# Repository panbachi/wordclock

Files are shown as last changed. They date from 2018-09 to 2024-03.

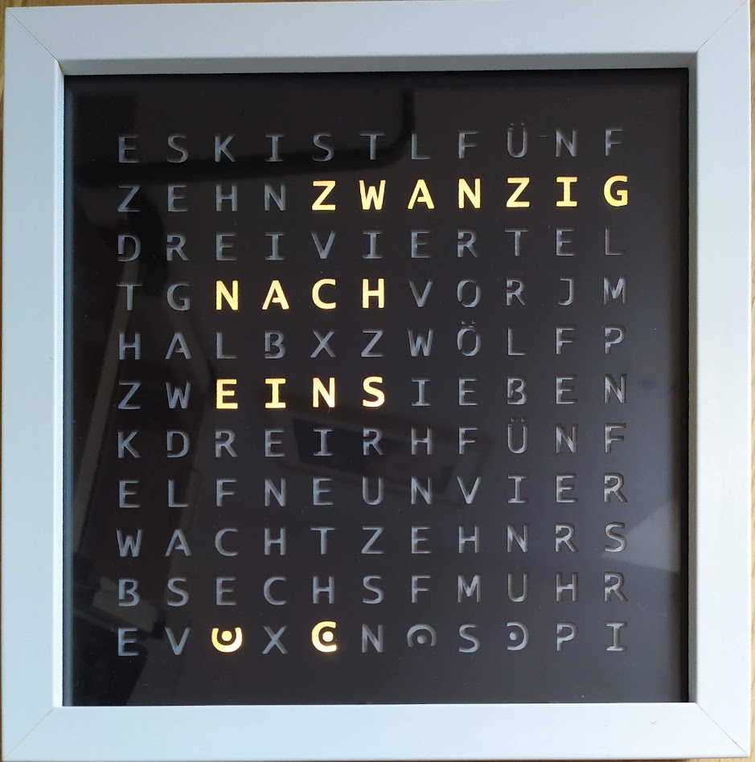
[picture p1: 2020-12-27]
graphics/plate/DE_de_s1.jpg

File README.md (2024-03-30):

# WordClock
 



**Font and german layout based on https://www.mikrocontroller.net/articles/Word_Clock**

# Requirements

## Healthcheck
* [FastLED](https://github.com/FastLED/FastLED)

## WordClock
* [FastLED](https://github.com/FastLED/FastLED)
* [NTPClient](https://github.com/arduino-libraries/NTPClient)
* [WifiManager](https://github.com/tzapu/WiFiManager)
* [ArduinoJson](https://github.com/bblanchon/ArduinoJson)

# Assemble
Word-Clock - Die WLAN Wort-Uhr zum selber bauen (https://www.youtube.com/watch?v=FvAM1t0tISE)

# Customizations
## Modify `user_config.h` to change config
| Key | Values | Comment |
|---|---|---|
| GRID_ROWS | 10<br>11 | count of rows |
| GRID_COLS | 11 | count of cols |
| GRID_FIRST | 0: top-left<br>1: top-right<br>2: buttom-left<br>3: buttom-right | position of first led |
| GRID_LANGUAGE | de_DE: german<br>de_DE_alt: german alternative | langauge |
| GRID_SINGLE_MINUTES | 0: before<br>1: after | position of minutes leds |

# Installation
Make your Arduino ready for Wemos D1 mini e.g. https://makesmart.net/blog/read/esp8266-d1-mini-programmieren-der-start-mit-der-arduino-ide
- Change the grid settings in the `wordclock/user_config.h`.
- Upload the sketch `wordclock/wordclock.ino` to your Wemos D1 mini (or other ESP8266).
- Enjoy

# Usage
The WordClock creates a WiFi-Hotspot with the name "WordClock". Connect e.g. your smartphone to the hotspot and you will be forwared to the config page, where you can set the WiFi credentials.
Check in your router what IP-adress your WordClock got. Open a webbrowser and go to `http://[YOUR_WORDCLOCK_IP]`. For (example) the IP-adress `192.168.178.20` go to `http://192.168.178.20`.

# Functions

## Set color
You can set a foreground and background color on your clock.

## Set time offset
You can set a time offset to specify your timezone.

## Set DND
You can set a time span in which the clock should be switched off.

## PWA
You can use the webbrowser function "Add to start screen" to install the webinterface as an app to your android (and possibly ios) smartphone.

# Create own grid-layout
To create your own grid-layout visit the Wiki: [Create Grid-Layout](https://github.com/panbachi/wordclock/wiki/Create-Grid-Layout)

# Support me / Follow me






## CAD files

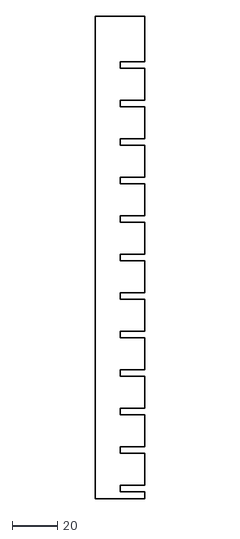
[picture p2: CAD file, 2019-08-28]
graphics/grid/grid_element_medium.dxf
22.0 x 213.0

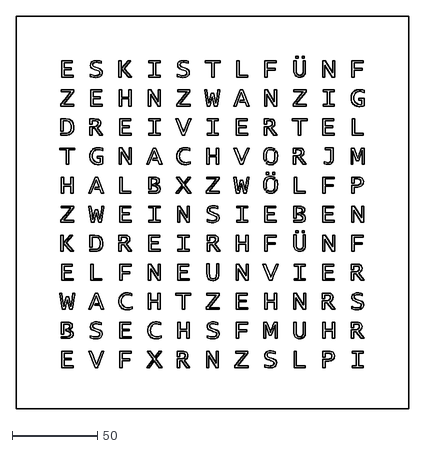
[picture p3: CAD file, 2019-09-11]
graphics/plate/de.dxf
230.0 x 230.0

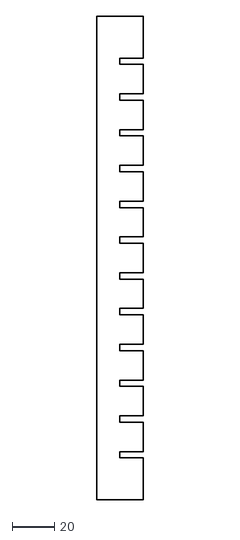
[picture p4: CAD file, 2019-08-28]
graphics/grid/grid_element_large.dxf
22.0 x 230.0

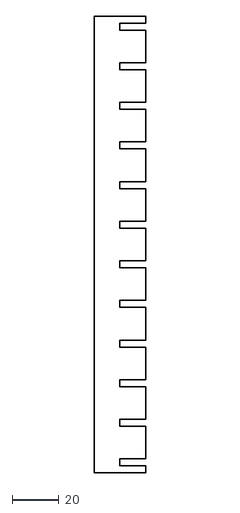
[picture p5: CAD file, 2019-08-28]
graphics/grid/grid_element_small.dxf
22.0 x 196.0

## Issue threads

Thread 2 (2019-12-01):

Minutenanzeige,

christianvoss90, 2019-12-01:
Vielen Dank erstmal für den schönen Code ;-)
Ich habe den Code bei mir um eine Minutenanzeige erweitert (in jeder Ecke der Uhr eine LED, die dann die Minuten 1-4, die auf die angezeigte Zeit addiert werden müssen, anzeigen).
Dabei ist mir aufgefallen, das mit dem originalen Code die Uhr eine Minute nach geht. Das Problem habe ich in Zeile 638 bis 642 (Originaler Code) gefunden. Die Zeilen 640 & 641 müssen vor den Zeilen 638 & 339 kommen (es müssen erst die Minuten und Stunden in die Variablen geschrieben werden, und dann das "show()" aufgerufen werden.
Dann habe ich den Code noch so angepasst, dass im setup einmal das Setzen der Zeitzone (die ich beim deklarieren der Variable: int offset = 1;) ausgeführt wird. So muss ich nicht nach jedem reboot des Controllers die Zeit neu setzten. Ausserdem habe ich den Code so angepasst, dass um 1:00 Uhr nicht "ES IST EINS UHR" erscheint, sondern auf das S verzichtet wird.

Vielleicht ist es ja etwas für den Code, oder jemand anderes kann damit auch was anfangen.

Hier einmal mein Code:

```
#include <ESP8266WiFi.h>
#include <ESP8266WebServer.h>
#include <FastLED.h>
#include <NTPClient.h>
#include <WiFiUdp.h>

#define NUM_LEDS 125
#define DATA_PIN D4

/**********************
 * SET WIFI CREDENTIALS
 **********************/
const char* ssid  = "DeinWlanName";
const char* password = "DeinWlanSchlüssel";

typedef struct {
  int r;
  int g;
  int b;
} color_t;

typedef struct {
  int pixel;
  int r;
  int g;
  int b;
} pixel_color_t;

int time_it_is[] = {110, 111, 113, 114, 115};// ES IST

int time_minutes[][12] = {
  { 13,  12,  11,  -1,  -1,  -1,  -1,  -1,  -1,  -1,  -1,  -1},//UHR
  {117, 118, 119, 120,  85,  84,  83,  82,  -1,  -1,  -1,  -1},//FÜNF NACH
  {109, 108, 107, 106,  85,  84,  83,  82,  -1,  -1,  -1,  -1},//ZEHN NACH
  { 92,  93,  94,  95,  96,  97,  98,  85,  84,  83,  82,  -1},//VIERTEL NACH
  {105, 104, 103, 102, 101, 100,  99,  85,  84,  83,  82,  -1},//ZWANZIG NACH
  {117, 118, 119, 120,  81,  80,  79,  66,  67,  68,  69,  -1},//FÜNF VOR HALB
  { 66,  67,  68,  69,  -1,  -1,  -1,  -1,  -1,  -1,  -1,  -1},//HALB
  {117, 118, 119, 120,  85,  84,  83,  82,  66,  67,  68,  69},//FÜNF NACH HALB
  {105, 104, 103, 102, 101, 100,  99,  81,  80,  79,  -1,  -1},//ZWANZIG VOR
  { 92,  93,  94,  95,  96,  97,  98,  81,  80,  79,  -1,  -1},//VIERTEL VOR
  {109, 108, 107, 106,  81,  80,  79,  -1,  -1,  -1,  -1,  -1},//ZEHN VOR
  {117, 118, 119, 120,  81,  80,  79,  -1,  -1,  -1,  -1,  -1} //FÜNF VOR
};

int time_hours[][6] = {
  {71, 72, 73, 74, 75, -1},//ZWÖLF
  {63, 62, 61, 60, -1, -1},//EINS
  {65, 64, 63, 62, -1, -1},//ZWIE
  {45, 46, 47, 48, -1, -1},//DREI
  {36, 35, 34, 33, -1, -1},//VIER
  {51, 52, 53, 54, -1, -1},//FÜNF
  {20, 19, 18, 17, 16, -1},//SECHS
  {60, 59, 58, 57, 56, 55},//SIEBEN
  {23, 24, 25, 26, -1, -1},//ACHT
  {40, 39, 38, 37, -1, -1},//NEUN
  {27, 28, 29, 30, -1, -1},//ZEHN
  {43, 42, 41, -1, -1, -1},//ELF
  {63, 62, 61, -1, -1, -1},//EIN
};

int time_ecken[][4] = {
  {-1, -1, -1, -1}, // ALLE AUS
  {122, -1, -1, -1}, //OBEN LINKS
  {122, 121, -1, -1},// +OBEN RECHTS
  {122, 121, 123, -1},//+UNTEN LINKS
  {122, 121, 123, 124},//+UNTEN RECHTS
};

int degree_minus[] = {108, 107, 106, 105};

int degree_symbol[] = { 119, 101, 99, 97};

int degree_10[] = {70, 61, 48, 39, 26, 17, 4};
int degree_20[] = {67, 68, 69, 70, 61, 48, 42, 41, 40, 39, 23, 20, 1, 2, 3, 4};
int degree_30[] = {67, 68, 69, 70, 61, 48, 42, 41, 40, 39, 26, 17, 1, 2, 3, 4};
int degree_40[] = {67, 70, 64, 61, 45, 48, 42, 41, 40, 39, 26, 17, 4};

int degree_0[] = {72, 73, 74, 75, 59, 56, 50, 53, 37, 34, 28, 31, 15, 12, 6, 7, 8, 9};
int degree_1[] = {75, 56, 53, 34, 31, 12, 9};
int degree_2[] = {72, 73, 74, 75, 56, 53, 37, 36, 35, 34, 28, 15, 6, 7, 8, 9};
int degree_3[] = {72, 73, 74, 75, 56, 53, 37, 36, 35, 34, 31, 12, 6, 7, 8, 9};
int degree_4[] = {72, 75, 59, 56, 50, 53, 37, 36, 35, 34, 31, 12, 9};
int degree_5[] = {72, 73, 74, 75, 59, 50, 37, 36, 35, 34, 31, 12, 6, 7, 8, 9};
int degree_6[] = {72, 73, 74, 75, 59, 50, 37, 36, 35, 34, 28, 31, 15, 12, 6, 7, 8, 9};
int degree_7[] = {72, 73, 74, 75, 56, 53, 34, 31, 12, 9};
int degree_8[] = {72, 73, 74, 75, 59, 56, 50, 53, 37, 36, 35, 34, 28, 31, 15, 12, 6, 7, 8, 9};
int degree_9[] = {72, 73, 74, 75, 59, 56, 50, 53, 37, 36, 35, 34, 31, 12, 6, 7, 8, 9};

pixel_color_t icon_snow[] = {
  { 5, 212, 223, 244 }, { 6, 176, 208, 247 }, { 7, 169, 206, 246 }, { 8, 207, 229, 249 }, { 14, 213, 232, 249 },
  { 15, 114, 175, 239 }, { 16, 86, 159, 237 }, { 17, 86, 159, 237 }, { 18, 155, 198, 244 }, { 19, 233, 233, 233 },
  { 23, 255, 255, 255 }, { 24, 201, 223, 245 }, { 25, 168, 203, 245 }, { 26, 171, 205, 245 }, { 27, 96, 165, 238 },
  { 28, 86, 159, 237 }, { 29, 86, 159, 237 }, { 30, 86, 159, 237 }, { 31, 200, 224, 249 }, { 34, 229, 246, 255 },
  { 35, 193, 220, 245 }, { 36, 166, 205, 244 }, { 37, 86, 159, 237 }, { 38, 86, 159, 237 }, { 39, 86, 159, 237 },
  { 40, 86, 159, 237 }, { 41, 86, 159, 237 }, { 42, 86, 159, 237 }, { 43, 94, 164, 238 }, { 44, 202, 223, 246 },
  { 45, 168, 205, 244 }, { 46, 86, 159, 237 }, { 47, 86, 159, 237 }, { 48, 86, 159, 237 }, { 49, 86, 159, 237 },
  { 50, 86, 159, 237 }, { 51, 86, 159, 237 }, { 52, 86, 159, 237 }, { 53, 86, 159, 237 }, { 54, 86, 160, 237 },
  { 55, 191, 219, 247 }, { 56, 166, 203, 245 }, { 57, 86, 159, 237 }, { 58, 86, 159, 237 }, { 59, 86, 159, 237 },
  { 60, 86, 159, 237 }, { 61, 86, 159, 237 }, { 62, 86, 159, 237 }, { 63, 86, 159, 237 }, { 64, 86, 159, 237 },
  { 65, 86, 159, 237 }, { 66, 168, 205, 244 }, { 67, 202, 223, 246 }, { 68, 96, 165, 238 }, { 69, 86, 159, 237 },
  { 70, 89, 161, 237 }, { 71, 93, 163, 238 }, { 72, 86, 159, 237 }, { 73, 86, 159, 237 }, { 74, 86, 159, 237 },
  { 75, 86, 159, 237 }, { 76, 86, 159, 237 }, { 77, 184, 215, 245 }, { 78, 204, 221, 238 }, { 79, 180, 212, 245 },
  { 80, 148, 194, 242 }, { 81, 210, 228, 245 }, { 82, 156, 199, 241 }, { 83, 145, 193, 242 }, { 84, 193, 219, 244 },
  { 85, 182, 214, 243 }, { 86, 161, 201, 244 }, { 87, 198, 220, 245 }, { 88, 176, 176, 176 }, { 91, 187, 187, 187 },
  { 92, 225, 225, 225 }, { 93, 225, 225, 225 }, { 94, 225, 225, 225 }, { 95, 226, 226, 226 }, { 96, 244, 244, 238 },
  { 97, 225, 225, 225 }, { 103, 237, 237, 237 }, { 104, 139, 139, 139 }, { 106, 246, 246, 237 }, { 107, 239, 239, 235 },
  { 114, 245, 245, 236 }, { 115, 241, 241, 241 }, { 117, 231, 231, 231 }, { 118, 251, 251, 243 }
};

pixel_color_t icon_thunder[] = {
  { 5, 206, 226, 244 }, { 6, 172, 208, 247 }, { 7, 165, 204, 244 }, { 8, 201, 224, 249 }, { 14, 213, 231, 249 },
  { 15, 110, 173, 239 }, { 16, 86, 159, 237 }, { 17, 86, 159, 237 }, { 18, 152, 195, 243 }, { 19, 239, 239, 239 },
  { 20, 255, 255, 255 }, { 23, 223, 223, 223 }, { 24, 193, 220, 247 }, { 25, 157, 198, 243 }, { 26, 171, 207, 245 },
  { 27, 114, 175, 240 }, { 28, 107, 172, 239 }, { 29, 97, 166, 238 }, { 30, 86, 159, 237 }, { 31, 199, 224, 246 },
  { 34, 217, 233, 249 }, { 35, 182, 212, 243 }, { 36, 156, 197, 243 }, { 37, 86, 159, 237 }, { 38, 211, 211, 197 },
  { 39, 239, 193, 104 }, { 40, 241, 198, 118 }, { 41, 230, 217, 185 }, { 42, 86, 159, 237 }, { 43, 89, 161, 237 },
  { 44, 196, 219, 245 }, { 45, 166, 204, 244 }, { 46, 86, 159, 237 }, { 47, 86, 159, 237 }, { 48, 99, 166, 238 },
  { 49, 230, 207, 156 }, { 50, 254, 164, 0 }, { 51, 237, 198, 122 }, { 52, 102, 168, 239 }, { 53, 86, 159, 237 },
  { 54, 86, 159, 237 }, { 55, 185, 214, 246 }, { 56, 164, 201, 243 }, { 57, 86, 159, 237 }, { 58, 86, 159, 237 },
  { 59, 230, 217, 185 }, { 60, 254, 171, 12 }, { 61, 250, 178, 46 }, { 62, 230, 217, 185 }, { 63, 86, 159, 237 },
  { 64, 86, 159, 237 }, { 65, 86, 159, 237 }, { 66, 172, 207, 243 }, { 67, 206, 224, 246 }, { 68, 115, 175, 239 },
  { 69, 86, 159, 237 }, { 70, 181, 209, 234 }, { 71, 230, 217, 185 }, { 72, 243, 194, 99 }, { 73, 254, 164, 0 },
  { 74, 215, 207, 181 }, { 75, 86, 159, 237 }, { 76, 89, 160, 237 }, { 77, 192, 219, 246 }, { 78, 203, 214, 214 },
  { 79, 195, 218, 245 }, { 80, 174, 208, 243 }, { 81, 233, 227, 208 }, { 82, 250, 178, 46 }, { 83, 254, 180, 46 },
  { 84, 232, 223, 203 }, { 85, 170, 207, 243 }, { 86, 178, 211, 245 }, { 87, 207, 221, 240 }, { 93, 165, 165, 165 },
  { 94, 251, 228, 183 }, { 95, 243, 194, 99 }, { 96, 92, 92, 92 }, { 103, 249, 233, 209 }, { 104, 237, 198, 122 },
  { 105, 208, 208, 208 }, { 117, 228, 228, 228 }, { 118, 251, 242, 225 }
};

pixel_color_t icon_rain[] = {
  { 5, 206, 226, 244 }, { 6, 174, 207, 243 }, { 7, 165, 204, 244 }, { 8, 203, 226, 249 }, { 14, 213, 231, 249 },
  { 15, 110, 173, 239 }, { 16, 86, 159, 237 }, { 17, 86, 159, 237 }, { 18, 152, 195, 243 }, { 19, 239, 239, 239 },
  { 20, 255, 255, 255 }, { 23, 223, 223, 223 }, { 24, 193, 220, 247 }, { 25, 155, 198, 243 }, { 26, 158, 200, 244 },
  { 27, 93, 163, 238 }, { 28, 86, 159, 237 }, { 29, 86, 159, 237 }, { 30, 86, 159, 237 }, { 31, 199, 224, 246 },
  { 34, 218, 228, 244 }, { 35, 182, 212, 245 }, { 36, 154, 196, 243 }, { 37, 86, 159, 237 }, { 38, 86, 159, 237 },
  { 39, 86, 159, 237 }, { 40, 86, 159, 237 }, { 41, 86, 159, 237 }, { 42, 86, 159, 237 }, { 43, 89, 161, 237 },
  { 44, 196, 219, 245 }, { 45, 166, 204, 244 }, { 46, 86, 159, 237 }, { 47, 86, 159, 237 }, { 48, 86, 159, 237 },
  { 49, 86, 159, 237 }, { 50, 86, 159, 237 }, { 51, 86, 159, 237 }, { 52, 86, 159, 237 }, { 53, 86, 159, 237 },
  { 54, 86, 159, 237 }, { 55, 185, 215, 245 }, { 56, 166, 203, 245 }, { 57, 86, 159, 237 }, { 58, 86, 159, 237 },
  { 59, 86, 159, 237 }, { 60, 86, 159, 237 }, { 61, 86, 159, 237 }, { 62, 86, 159, 237 }, { 63, 86, 159, 237 },
  { 64, 86, 159, 237 }, { 65, 86, 159, 237 }, { 66, 172, 207, 243 }, { 67, 205, 224, 246 }, { 68, 116, 175, 239 },
  { 69, 86, 159, 237 }, { 70, 86, 159, 237 }, { 71, 86, 159, 237 }, { 72, 86, 159, 237 }, { 73, 86, 159, 237 },
  { 74, 86, 159, 237 }, { 75, 86, 159, 237 }, { 76, 89, 161, 237 }, { 77, 192, 219, 246 }, { 78, 203, 214, 214 },
  { 79, 191, 218, 245 }, { 80, 165, 202, 244 }, { 81, 169, 204, 243 }, { 82, 164, 203, 244 }, { 83, 161, 201, 245 },
  { 84, 169, 204, 243 }, { 85, 165, 204, 244 }, { 86, 165, 203, 244 }, { 87, 207, 226, 245 }, { 91, 140, 187, 241 },
  { 92, 127, 177, 227 }, { 94, 138, 186, 239 }, { 95, 139, 181, 230 }, { 97, 140, 186, 243 }, { 98, 127, 179, 231 },
  { 101, 121, 166, 232 }, { 102, 138, 184, 242 }, { 104, 122, 169, 207 }, { 105, 130, 183, 231 }, { 107, 127, 145, 182 },
  { 108, 123, 177, 231 }, { 113, 137, 180, 239 }, { 114, 127, 178, 229 }
};

pixel_color_t icon_sun[] = {
  { 6, 253, 164, 0 }, { 13, 255, 166, 0 }, { 14, 255, 160, 0 }, { 17, 253, 163, 0 }, { 20, 255, 160, 0 },
  { 21, 255, 166, 0 }, { 24, 243, 156, 0 }, { 25, 253, 163, 0 }, { 26, 235, 156, 0 }, { 28, 226, 169, 0 },
  { 30, 235, 156, 0 }, { 31, 253, 163, 0 }, { 32, 243, 156, 0 }, { 36, 245, 160, 0 }, { 37, 243, 160, 0 },
  { 38, 253, 162, 0 }, { 39, 253, 163, 0 }, { 40, 253, 164, 0 }, { 41, 248, 163, 0 }, { 42, 245, 160, 0 },
  { 48, 253, 162, 0 }, { 49, 254, 164, 0 }, { 50, 254, 164, 0 }, { 51, 254, 164, 0 }, { 52, 253, 162, 0 },
  { 56, 253, 165, 0 }, { 57, 253, 165, 0 }, { 58, 207, 127, 0 }, { 59, 253, 163, 0 }, { 60, 254, 164, 0 },
  { 61, 254, 164, 0 }, { 62, 254, 164, 0 }, { 63, 253, 163, 0 }, { 64, 207, 127, 0 }, { 65, 253, 165, 0 },
  { 66, 253, 165, 0 }, { 70, 253, 163, 0 }, { 71, 254, 164, 0 }, { 72, 254, 164, 0 }, { 73, 254, 164, 0 },
  { 74, 253, 164, 0 }, { 80, 238, 153, 0 }, { 81, 232, 160, 0 }, { 82, 253, 163, 0 }, { 83, 253, 162, 0 },
  { 84, 253, 161, 0 }, { 85, 238, 158, 0 }, { 86, 238, 153, 0 }, { 90, 243, 158, 0 }, { 91, 253, 162, 0 },
  { 92, 238, 153, 0 }, { 94, 159, 127, 0 }, { 96, 238, 153, 0 }, { 97, 253, 162, 0 }, { 98, 243, 158, 0 },
  { 101, 245, 160, 0 }, { 102, 243, 158, 0 }, { 105, 253, 161, 0 }, { 108, 243, 158, 0 }, { 109, 245, 160, 0 },
  { 116, 253, 163, 0 }
};
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
napsio, 2019-12-12:
Das und mehr ist in der neuen Version möglich.

Closed 2019-12-12.

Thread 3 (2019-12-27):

LEDs are not working

bastifix, 2019-12-27:
The LEDs are working with neopixel as in this example:
http://noob-nerd.de/nodemcu-led-effekt-via-ws2812b/

It seems that my WS2812B and FastLed won't work together.
I also tried several FastLed versions.

Do you have any idea?

Thanks!

bastifix, 2019-12-28:
Oh, how stupid, I use pin D4, so I typed D4 instead of 4:

`#define DATA_PIN 4`

Not it works like a charm!
Thanks very much!!!

Closed 2019-12-28.

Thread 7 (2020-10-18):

Frage zu Minuten LED´s

obkram, 2020-10-18:
Hallo lieber Entwickler,

vorab bedanke ich mich bei Ihnen für die Möglichkeit dieses tolle Projekt nachbauen zu dürfen.

Hierbei handelt es sich weniger um einen Issue sondern mehr um eine Anfrage.

**Mein Aufbau**:
In meinem Fall habe ich ein Grid von 11x11 LEDs, Minutenposition after und Start LED unten links bei Draufsicht gewählt.
Auf vier zusätzliche LED habe ich wegen der schmalen Bauform des RIBBA Rahmens verzichtet.

Meine Frage wäre nun ob ich evtl. in der Konfiguration die Position der Minuten LEDs selbst ändern kann und wenn ja wo. Bei dem von Ihnen vorgegebenen Grid Layout besteht bei einer LED Bestückung von 11x11 LEDs die unterste Zeile aus der Buchstabenreihe **"E-V-F-X-R-N-Z-S-L-P-I"**.
Dies scheint ja ein optischer Platzhalter zu sein da sich hieraus keine Wörter Bilden lassen. Ich hatte mir vorgestellt hier die Positionen **"F R Z L"** für die Minuten zu missbrauchen.

Sollte dies möglich sein dann würde ich mich über einen Hinweis freuen. Ansonsten Anfrage bitte einfach ignorieren und schliessen. Vielen Dank im Voraus.

LG Sven O.

obkram, 2020-10-20:
Hallo nochmal,

ich habe es für mich jetzt zumindest schon einmal soweit eingegrenzt das ich bei Änderung der ersten Minuten-LED-Position in der Zeile 62 in der Datei de_DE.cpp die Minutenanzeige an die Position 112 bekomme.
Vielleicht hat ja jemand eine Idee wie ich die Formel ...

_for(int s = (NUM_LEDS - _**"neue LED POSITION"**_); s < (NUM_LEDS **_"neue LED POSITION"_** + singleMinute); s++)_

...so abändern kann die singleMinute nicht an der Position bspw. 112-115 angezeigt werden sondern an den Positionen 112, 114, 116 und 118. Also immer eine singleMinute + ein Platzhalter für die folgende LED.

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

LG Sven O.

napsio, 2020-10-20:
Hi,

du kannst mal folgendes probieren (ungetestet):

```c
  if(GRID_SINGLE_MINUTES == 1) {
	// single minutes
        if(singleMinute >= 1) {
	  Led::ids[112].setRGB(Config::color_fg.r, Config::color_fg.g, Config::color_fg.b);
        }
        if(singleMinute >= 2) {
	  Led::ids[114].setRGB(Config::color_fg.r, Config::color_fg.g, Config::color_fg.b);
        }
        if(singleMinute >= 3) {
	  Led::ids[116].setRGB(Config::color_fg.r, Config::color_fg.g, Config::color_fg.b);
        }
        if(singleMinute >= 4) {
	  Led::ids[118].setRGB(Config::color_fg.r, Config::color_fg.g, Config::color_fg.b);
        }
  } else {
	for(int s = 0; s < singleMinute; s++) {
	  Led::ids[s].setRGB(Config::color_fg.r, Config::color_fg.g, Config::color_fg.b);
	}
  }
```
Ist zwar nicht die schönste Lösung, müsste aber funktionieren :)

obkram, 2020-10-20:
Hallo napsio,

vielen Dank für die schnelle Antwort. Ich habe es sofort getestet und es funktioniert einwandfrei. Ich musste lediglich die LED IDs auf 2,4,6 und 8 abändern. Dies hat scheinbar seinen Ursprung darin, das ich von unten links anfangen muss zu zählen, da dort mein Einspeisepunkt ist.
Vielleicht könnte das ja mit den Auswahloptionen wie unten angegeben von panbachi in den Master mit aufgenommen werden.

 * 0: before
 * 1: last
 * 2: after
 */
#define GRID_SINGLE_MINUTES 1

Vielen Dank für die Hilfe napsio.

LG Sven O.

obkram, 2020-10-24:
Hallo napsio,

anbei sende ich dir ein Bild wie die Darstellung bei mir
![Uploading A2FE3B57-DBEC-403E-B9DC-387E5C465767.jpeg…]()
nun aussieht. Danke nochmal.

LG Sven O.

Closed 2020-10-20.

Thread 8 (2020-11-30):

Hour jumping

valknut89, 2020-11-30:
I think I found a mistake. I have a grid in Config of 10×11 and DE_alt.
The the hour jumps back and forth between the correct hour and an hour before. every two minutes

fabmsg, 2020-11-30:
I have been facing that issue for some time. What did you change to correct it?

achkoe, 2020-11-30:
I am facing this issue too. For example between 19:25 and 19:26 there seems to be a difference of 1 hour in displayed time.

valknut89, 2020-11-30:
we debugged the time.cpp and found that the time zone query changes between 0 and 3600. the HTTP return is sometimes incorrect. So we changed the void loop() to
`void Time::loop() {
  Time::ntpClient.update();

  int h = Time::ntpClient.getHours();
  int m = Time::ntpClient.getMinutes();

  if(m != Time::minute) {
    if(m == 0 && h == Time::hour) {
       h = (h + 1) % 24;
    }

    Time::hour = h;
    Time::minute = m;
    Grid::setTime(Time::hour, Time::minute);
    Time::ntpClient.setTimeOffset(3600);
    Serial.println(h);

  }
}`

napsio, 2020-12-02:
Do you use the stable version (4.0.1) or the master branch?

SehlingS, 2020-12-04:
> Do you use the stable version (4.0.1) or the master branch?

I have the same problem with the master branch 4.0.1. But i think, only when i have activate the automatic time zone.

fabmsg, 2020-12-06:
I have the same issue even with the automatic timezone inactive.
is there an option do lock always the time zone and prevent this?

valknut89, 2020-12-06:
> Do you use the stable version (4.0.1) or the master branch?

I can only download one branch from here. So I took this branch

fabmsg, 2020-12-06:
Is it possible to fix the timezone? I cannot change it because is greyed out
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

SehlingS, 2020-12-07:
> Is it possible to fix the timezone? I cannot change it because is greyed out
> 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

YOu have to restart the device after you set it to inaktiv. then you have the possibility to change the time zone to mabey +1

ibrot, 2020-12-08:
Hi,

I had the same issue a while ago.  Back then it was jumping between 0 and 7200 because of the daylight saving time.

I fixed it that I did not use 0 as a fallback for the timezone, but using the last known timezone if we get a bad response from the time zone provider.

I am quite inexperienced with github therefore I do not yet know what the correct process would be to provide my commit as an possible solution for this issue.
But for now, here is the link to the commit inside my fork of this project: https://github.com/ibrot/wordclock/commit/72ab3a5aa16a46fec0ffced95814837e2d1ac4c4

napsio, 2020-12-12:
This might be only an issue for the master branch. The release 4.0.1 does not have automatic timezones. I'll check the #10 pull-request.

valknut89, 2020-12-12:
where can i download 4.0.1 ?

napsio, 2020-12-12:
Look at: [https://github.com/panbachi/wordclock/releases](https://github.com/panbachi/wordclock/releases)

valknut89, 2020-12-12:
thank you for your great work

valknut89, 2020-12-16:
In Master-Branch the Option "Automatische Zeitzone" is reset to "Aktiv" after set "Inaktiv" and coldstart ESP.

SehlingS, 2020-12-17:
i can confirm that, but the automatic will work fine with the last changes from ibrot.

LoenzeDoenz, 2020-12-18:
"Automatische Zeitzone" for me in germany is not working.. offset is not correct. Also Manual offset is not working.

SehlingS, 2020-12-19:
I can send you a ready to flash bin to test it out.
Maybe you use other libarys.

valknut89, 2020-12-19:
> In Master-Branch the Option "Automatische Zeitzone" is reset to "Aktiv" after set "Inaktiv" and coldstart ESP.

I fixed it for me in line 45, set it to `Config::automatic_timezone = doc["tz_auto"].as<int>() == `1;``

AndreUwePeters, 2021-01-03:
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

also with this one the automatic modus ist still one hour wrong..  but is seems to be constantly wrong and dosent jump anymore

valknut89, 2021-01-04:
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

With this version there is no automatic mode. It isn't wrong, it is fixed to a special timezone. The webinterface has to ne changed too With this time.cpp.

p3moto, 2021-01-04:
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

the time still jumpes...

i added this lines
	Time::ntpClient.setTimeOffset(3600);
	Serial.println(h);
in the code of the time.cpp, like:
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

"The webinterface has to be changed too With this time.cpp."
no it did not change anything there... still could use automatic timezone

maybe i missunderstood sth. i dont have a clue of C++.

valknut89, 2021-01-04:
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

pls have a look at https://github.com/panbachi/wordclock/issues/9#issuecomment-740008946

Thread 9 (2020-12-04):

farylink xxx AP visibale after Connection to a Network

SehlingS, 2020-12-04:
Hey,
my Wordclock is connceted to my 2.4 Ghz Wlan but the own unsecured AcessPoint is still visible.
But not the one named with wordclock the name is farylink XXXX. How can i disabel this wlan ap?
I have found that Thread with maybe a solution: https://forum.arduino.cc/index.php?topic=493972.0

best regards
Sascha

SehlingS, 2020-12-04:
i have solved the problem by adding the following row to the wifi.cpp file.
WiFi.mode(WIFI_STA);

Then there is only 1 AP (Wordclock) avalible and after setting the wlan password and ssid, all networks are closed.

valknut89, 2020-12-06:
I had this too. I changed it. Now my AP shows only up, if I press the reset button of my D1 twice. Because I added an RTC Chip, so that I dont need Wifi permanently.

SehlingS, 2020-12-07:
> I had this too. I changed it. Now my AP shows only up, if I press the reset button of my D1 twice. Because I added an RTC Chip, so that I dont need Wifi permanently.

Can you share us your solution?

valknut89, 2020-12-07:
wifi.cpp:

#include <ESP8266WiFi.h>
#include <WiFiManager.h>
#include <DoubleResetDetector.h>
#include "wifi.h"

// Number of seconds after reset during which a
// subseqent reset will be considered a double reset.
#define DRD_TIMEOUT 10

// RTC Memory Address for the DoubleResetDetector to use
#define DRD_ADDRESS 0

DoubleResetDetector drd(DRD_TIMEOUT, DRD_ADDRESS);

void Wifi::setup() {

WiFi.hostname("WordClock");
WiFiManager wifiManager;
 if (drd.detectDoubleReset()) {
    Serial.println("Double Reset Detected");
    wifiManager.autoConnect("WordClock");
  } else {
    Serial.println("No Double Reset Detected");
  }
}

void Wifi::reset() {
  WiFi.disconnect(true);
}

valknut89, 2020-12-07:
time.cpp:

#include <Arduino.h>
#include <NTPClient.h>
#include <WiFiUdp.h>
#include <ESP8266WiFi.h>
#include "time.h"
#include "grid.h"
#include "utcOffset.h"

//RTC
#include <Wire.h>
#include "RTClib.h"

RTC_DS3231 rtc;

char daysOfTheWeek[7][12] = {"Sunday", "Monday", "Tuesday", "Wednesday", "Thursday", "Friday", "Saturday"};

void Time::setup() {
Time::ntpClient.setTimeOffset(3600);
Time::ntpClient.begin();
Time::ntpClient.update();

#ifndef ESP8266
  while (!Serial); // for Leonardo/Micro/Zero
#endif

 // Serial.begin(9600);

//delay(3000); // wait for console opening

  if (! rtc.begin()) {
    Serial.println("Couldn't find RTC");
  }

}

void Time::loop() {
 int h;
 int m;
 int s;
  if (WiFi.status() == WL_CONNECTED) {
Serial.println("verbunden");
  Time::ntpClient.update();
  h = Time::ntpClient.getHours();
  m = Time::ntpClient.getMinutes();
  s = Time::ntpClient.getSeconds();
  if (rtc.begin()) {
    rtc.adjust(DateTime(2014, 1, 21, h, m, s));}
  //Serial.println("m0");
//Serial.println(m);
}

  else { if (rtc.begin()) {
DateTime now = rtc.now();
       h = now.hour();
       m = now.minute();
       } }

  if(m != Time::minute) {
    if(m == 0 && h == Time::hour) {
      h = (h + 1) % 24;
    }

    Time::hour = h;
    Time::minute = m;

Grid::setTime(Time::hour, Time::minute);
    Time::ntpClient.setTimeOffset(3600);

  }
}

int Time::hour = -1;
int Time::minute = -1;
WiFiUDP Time::udp;
NTPClient Time::ntpClient = NTPClient(Time::udp);

napsio, 2020-12-12:
@SehlingS Thanks for the tip. It seems to depend on the version of the WiFiManger library. I could not reproduce it with an older version of the lib.

@valknut89 Thanks for your code. What RTC module do you use for the clock?

SehlingS, 2020-12-13:
Can you add this part to your wifi.cpp file.
WiFi.mode(WIFI_STA);

I think that has no negative effect ;-).

valknut89, 2020-12-13:
> @SehlingS Thanks for the tip. It seems to depend on the version of the WiFiManger library. I could not reproduce it with an older version of the lib.
>
> @valknut89 Thanks for your code. What RTC module do you use for the clock?

The DS3231

napsio, 2020-12-16:
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

I've added the line to the master branch.

SehlingS, 2020-12-16:
Thx

p3moto, 2021-01-06:
i downloadad the files 4.0.1 an changed these code here:

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

and this

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

and also
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

my clock just shows the white "E" für a second an then jumps du a random time... then the clock is not reachabele for wifi anymore... not listed in the router or shows any register-wifi for login

sorry this dosent work at all, what did i do wrong?

valknut89, 2021-01-07:
OK, dann halt mal in Deutsch. Also: Die angepasste wifi.cpp sorgt dafür, dass der Access Point des ESP nur sichtbar wird, wenn man nach Stromzufuhr innerhalb von 10s zweimal den Reset-Taster drückt. Ist eine Optimierung, die ich für mich als gut befunden habe, mehr nicht. Kannst du also im Originalzustand belassen.
Was die Time.cpp angeht:
Das Skript, was ich ergänzt habe, sieht einen zusätzlichen RTC-Chip DS3231 vor, der die aktuelle Zeit speichert und auch bei Stromunterbrechung und OHNE WLAN die Zeit korrekt anzeigt. Hast du diesen Chip nicht, ist der Großteil des Skriptes auch für dich gar nicht relevant.

Zu deinem Problem:
Mach mal folgendes: Spiele dir die aktuelle Version 4.0.1 auf und setze die Zeitzone im Interface manuell, wenn möglich. Wenn das nicht geht, dann editiere die time.cpp mal wie folgt:

#include <Arduino.h>
#include <NTPClient.h>
#include <WiFiUdp.h>

#include "time.h"
#include "grid.h"

void Time::setup() {
  Time::ntpClient.setTimeOffset(3600);
  Time::ntpClient.begin();
  Time::ntpClient.update();
}

void Time::loop() {
  Time::ntpClient.update();

  int h = Time::ntpClient.getHours();
  int m = Time::ntpClient.getMinutes();

  if(m != Time::minute) {
	if(m == 0 && h == Time::hour) {
		h = (h + 1) % 24;
	}

    Time::hour = h;
    Time::minute = m;
    Grid::setTime(Time::hour, Time::minute);
    Time::ntpClient.setTimeOffset(3600);
  }
}

int Time::hour = -1;
int Time::minute = -1;
WiFiUDP Time::udp;
NTPClient Time::ntpClient = NTPClient(Time::udp);

p3moto, 2021-01-07:
@valknut89 vielen lieben Dank für die ausführlichen und verständlichen Erklärungen :)

Closed 2020-12-16.

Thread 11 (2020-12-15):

Brightness

valknut89, 2020-12-15:
Is it possible to change brightness in 4.0.1 ?
I only find the option in the "led.cpp" but I am not sure if it the right one.

Thx

napsio, 2020-12-16:
In version 4.0.1 you can only change the brightness by changing the color to a lighter or darker one.

SehlingS, 2020-12-16:
I'm a little bit confuesd.
I have cloned or download the master branch and with that version, i can addjust the brightness depending in on current.
But now i have seen that the version 4.0.1 under Releases has a other gui.cpp file without that function.
What is now the newest version and why has the master branch a other state as the last release.
Sorry but I'm a newbie here at github ;-)

napsio, 2020-12-16:
The master branch is newer and has additional functionality, but has still some bugs. When the bugs were fixed, it will be released as version 5.0.0. For now version 4.0.1 is the stable release.

SehlingS, 2020-12-16:
OK Thank you, i use the master branch, so I'm a beta tester ;-). But it works without any problems for now.
One additional thing, is it possibile to deactivate the blue led at the wemos? In one of my clock it shines out of it.

valknut89, 2020-12-16:
> In version 4.0.1 you can only change the brightness by changing the color to a lighter or darker one.

i tried the brightness control in master branch. i tested with 2000 mA and 10%, 100%. But the leds didn't change brightness. I tried restart too without success. Is there a trick or must I connect the led stripes directly to 5V supply ? I connected the stripe to wemos 5V GND and D4

SehlingS, 2020-12-17:
it works for me like you it should. I have conncet the stripes only to the wemos 5v, Gnd and D4 Pin.

valknut89, 2020-12-17:
I checked my ESP, its not a wemos D1. It is a D1 ESP8266MOD 12-F. Maybe thats the Problem? Do you have any Ideas?

SehlingS, 2020-12-17:
i have the same one. without any problems.
https://de.aliexpress.com/item/32651747570.html?spm=a2g0s.9042311.0.0.17dc4c4d61v0P4

valknut89, 2020-12-17:
> i have the same one. without any problems.
> https://de.aliexpress.com/item/32651747570.html?spm=a2g0s.9042311.0.0.17dc4c4d61v0P4

Your Brightness Settings working? Pls check 0% 10% till 100% if brightness is changing Top. Thx

SehlingS, 2020-12-17:
i use this one
https://de.aliexpress.com/item/32682015405.html?spm=a2g0s.9042311.0.0.17dc4c4d61v0P4
IP 30 60LED/m

it is changing, but only till 60% because i have set it to 1000mA.
I can adjust it in 5% steps.

valknut89, 2020-12-17:
which version do you use? I have only 10% steps Which version of fastLED library do you use?

SehlingS, 2020-12-17:
i use the newest libs which are availble in Arduino IDE.
Boardconfig is wemos d1 but if you select the wrong one, i got an error message.

I think is use a mix branch some parts from the master and some parts from the @ibrot fork.
But only because of the problems with the automatic time zone.

The brightness works also before i start to mix with the "10% Version"

SehlingS, 2020-12-17:
i can create you a bin file from my local programm. So, you can test if it works with that one.
What grid do you use? 11x11 with de_De ?

valknut89, 2020-12-17:
Ok. Thx I will try. I have a own Layout. So can send me your Version, that's best

SehlingS, 2020-12-19:
sorry for the delay, you can use my fork. This version is working for me without any problems.
Automatic tiem zone and brightness is wirking well for me in germany. ( +1)

valknut89, 2020-12-19:
Found the issue. I used DE_alt. In the cpp the line ''FastLED.setBrightness(Config::brightness * 255);'' was missing in master-branch and 4.0.1

Closed 2020-12-19.

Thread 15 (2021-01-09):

weitere Sprache/Dialekt (Kölsch)

p3moto, 2021-01-09:
Hallo zusammen,

ich habe mal versucht ohne jegliche C++ Kenntnisse eine weitere Sprache hinzuzufügen. Leider scheitere ich an dem Anpassen der Grids
Ich musste die Gridgröße anpassen, jedoch finde ich nichts wo das Grid vorher mit 5 und 12 bestimmt/initialisiert wird was dann zu den Problemen mit meinen geänderten 4 und 13 führt.
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

[kölsch.zip](https://github.com/panbachi/wordclock/files/5789825/kolsch.zip)

p3moto, 2021-01-09:
grade noch festgestellt, dass ich scheinbar hier noch die 13 einsetzen muss statt 12

>
> for(int m = 0; m < 13; m++) {
>

komischerweise wandert das einzelne "H" oben minutenweise immer weiter

napsio, 2021-01-22:
Vielen Dank. Ich werd mir das die Tage mal anschauen :)

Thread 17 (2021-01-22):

Funktioniert der 11x10 Modus schon? :)

SkylightXD, 2021-01-22:
Hi Panbachi,

funktioniert der 11x10 Modus schon richtig?
Ich habe es gerade getestet, aber irgendwie sah die Anzeige komisch aus ;)
Oder funktioniert die Eckenwahl für die erste LED nicht?
Kann ich den Minutenzähler auch ausschalten oder schreibe ich den ans Ende und schneide den Streifen ab? :)

Sorry für die vielen Fragen, ich hoffe es hilft dir :)

Grüße

SehlingS, 2021-01-29:
Ich habe selber eine 11x10 Varaiante am Laufen. Minuten LED einfach ans Ende, dann passt das ;-).

WolfgangFranke, 2021-05-22:
@SkylightXD can you please check #23 , ich habe damit im 11x10 Modus jetzt eine sinnvolle Anzeige.

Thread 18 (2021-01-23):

Feature: Helligkeit einstellbar

SkylightXD, 2021-01-23:
Was hältst du davon, wenn die Helligkeit der Uhr einstellbar wäre? Bzw. ggf. könntest du einen Helligkeitssensor ergänzen :)

Aktuell hast du wahrscheinlich den Strom begrenzt für den USB Port oder?

obkram, 2021-02-16:
Hallo panbachi,
ich muss mich der Frage von SkylightXD leider anschließen. Ich bin etwas verwundert, denn in dem Release was ich im Herbst letzten Jahres herunter geladen habe war das Einstellen der mA des Netzteils und die Helligkeit der LEDs
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
noch möglich. Jetzt ist in diesem Bereich allerdings alles blank. Ist das ein Versehen oder hat das einen Grund?

LG obkram

obkram, 2021-02-16:
![Uploading AD292EA7-727F-4B27-B966-A0EB5EBED4EE.jpeg…]()

obkram, 2021-02-17:
Ansonsten wäre es zumindest gut zu wissen wo die Defaultwerte abgelegt sind um die Stromstärke einmalig vor dem Hochladen des Sketches abändern zu können. Danke.
@napsio : oder hast du hier noch eine Idee?

obkram, 2021-02-17:
https://github.com/panbachi/wordclock/commit/009fa8652ee861f33a6df101f0468924afa49bb4

Die Änderungen aus dem Beitrag von Bernhard Petzold scheinen nicht mehr da zu sein. Zumindest in den Dateien die ich überflogen habe, u.A. config.cop. Ist es möglich das die Änderungen an der Timezoneproblematik auf einer älteren Version aufgebaut wurden?

obkram, 2021-02-18:
Ok, mein Fehler. Ich habe jetzt den Wordclock_Master heruntergeladen. da ist alles drin. Die Funktion zur Einstellung der Helligkeit fehlt nur im Wordclock 4.0.1 Release.

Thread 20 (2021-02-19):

LED Schlangenanordnung ändern

pL4uN3r, 2021-02-19:
Servus,
kann man in dem Code die Anordnung der Leds ändern? Hab des Ganze nicht schlangenförmig angeordnet. Ich habe von oben links beginnend die Streifen immer von links nach rechts angeordnet wie man ein Buch liest bzw. wie die Anordnung in der "Tabelle" (https://github.com/panbachi/wordclock/wiki/Create-Grid-Layout) ist. Habe die GRID_ROWS=10 GRID_COLS=11 Anordnung genommen.
Bin Recht neu in der Programmierung und kann nicht wirklich etwas im Code finden.
Hoffe ihr könnt mir auf einfachem Weg helfen.

SkylightXD, 2021-02-19:
Das ist leider nicht möglich... Die LEDs werden im Grunde nach ihrer Reihenfolge adressiert, also nacheinander. Bzw. die Adresse sagt aus, wie oft der Befehl weiter geschubst wird.
So wie du das jetzt aufgebaut hast, sind die LEDs parallel, haben also die gleiche Adresse

pL4uN3r, 2021-02-19:
Ja genau nach ihrer Reihenfolge welche wie folgt ist und so hab ich es auch "leider"
 verdrahtet:
 0  |  1  |  2  |  3  |  4  |  5  |  6  |  7  |  8  |  9  | 10
11 | 12 | 13 | 14 | 15 | 16 | 17 | 18 | 19 | 20 | 21
22 | 23 | 24 | 25 | 26 | 27 | 28 | 29 | 30 | 31 | 32
33 | 34 | 35 | 36 | 37 | 38 | 39 | 40 | 41 | 42 | 43

nur das sich jetzt folgende Reihenfolge ergibt:
10 |  9  |  8  |  7  |  6  |  5  |  4  |  3  |  2  |  1  |  0   <---
11 | 12 | 13 | 14 | 15 | 16 | 17 | 18 | 19 | 20 | 21
32 | 31 | 30 | 29 | 28 | 27 | 26 | 25 | 24 | 23 | 22   <---
33 | 34 | 35 | 36 | 37 | 38 | 39 | 40 | 41 | 42 | 43

so ist quasi jede 2. Reihe spiegelverkehrt.

habe zwar selber ein anderes Layout und musste dann bei jeder 2. Zeile umdenken mit den LEDs... Katastrophe -.-

Closed 2021-07-12.

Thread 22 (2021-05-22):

Compile error: obsolete API, use ::begin(WiFiClient, url) in "src/utcOffset.cpp"

WolfgangFranke, 2021-05-22:
Arduino IDE:    1.8.15 (Mac OS X)
Ard-ESP-Core:   https://arduino.esp8266.com/stable/package_esp8266com_index.json
ESP8266 Board:  LOLIN(WEMOS) D1 R2 & mini

Compile Error in "src/utcOffset.cpp":
```
/WordClock401_ESP8266/src/utcOffset.cpp: In static member function 'static void UtcOffset::updateLocalizedUtcOffset()':
/WordClock401_ESP8266/src/utcOffset.cpp:9:13: error: call to 'HTTPClient::begin' declared with attribute error: obsolete API, use ::begin(WiFiClient, url)
    9 |   http.begin("http://worldtimeapi.org/api/ip");

exit status 1
Fehler beim Kompilieren für das Board LOLIN(WEMOS) D1 R2 & mini.
```

WolfgangFranke, 2021-05-22:
that change works for me, please verify:

/* remove the depricated ESP8266 API call:
 *HTTPClient http;
 *http.begin("http://worldtimeapi.org/api/ip");
*/

//  use the new API like below:
  WiFiClient client;
  HTTPClient http;
  http.begin(client, "http://worldtimeapi.org/api/ip");`

Closed 2021-08-28.

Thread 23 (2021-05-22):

wrong definition of "GRID_FIRST : top-left" in user_config.h (Postition of first LED)

WolfgangFranke, 2021-05-22:
In "user_config.h " the definition of GRID_FIRST = 0 means "top-left", but does not show useful times on "top-left" strips.
Instead I had to use  GRID_FIRST = 1 for my strip starting "top-left" (links-oben), to get the correct times displayed.
Assumption: ("top-left" is looking at the front of the clock)

```
/* Postition of first LED
 *
 * Options
 * -------
 * 0: top-left              (bug:  1 work for top-left)
 * 1: top-right             (is that top-left then???)
 * 2: buttom-left
 * 3: buttom-right
 */
#define GRID_FIRST 1
```

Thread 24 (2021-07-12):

Erste LED wird grün nach Minutenwechsel

pL4uN3r, 2021-07-12:
Wie im Titel beschrieben wird die erste LED (Led 0; das "E" von "ES IST") färbt sich grün. Mir ist aufgefallen wenn man es mit einer anderen synchronisierten Uhr vergleicht, dann passiert wenn sich die "Minute" ändert. Also Spannung drauf alles gut und wenn jetzt die Minute von z.B. 27 auf 28 sich ändert, wird das "E" grün.

Bei meiner ersten Uhr war es nicht so und bei der jetzigen/zweiten ist halt dieser Fehler.
Hoffe mir kann da evtl. wer helfen?!

pL4uN3r, 2021-07-16:
Problem behoben. Mit einer älteren Boardversion (ESP8266 by ESP8266 Community) funktioniert es und zwar 2.7.4, aber der v3.0.0 tritt der Fehler auf.

napsio, 2021-07-28:
Perfekt. Vielen Dank für den Hinweis.

clemenstyp, 2021-08-19:
ansonsten sollte der LED Streifen einfach an D3 als Datenport angeschlossen werden. D4 ist mit der blauen Status LED auf dem Wemos Board gekoppelt und daher leuchtet dann die erste LED wenn die Status LED geändert wird.

Lutze53, 2021-08-19:
> ansonsten sollte der LED Streifen einfach an D3 als Datenport angeschlossen werden. D4 ist mit der blauen Status LED auf dem Wemos Board gekoppelt und daher leuchtet dann die erste LED wenn die Status LED geändert wird.

Nein das hat mit den D4 nix zu tun, es ist egal ab D3 oder D4 die erste LED leuchtet immer. Es liegt an der Boardversion ab 3.0 mit 2.74 ist das Problem behoben.

heikokehr, 2021-11-06:
na super, bin ich wenigstens nicht der einzige, der das Problem mit der ersten (0) hat.
Hab auch schon andere DIO s getestet und auch mit 1K Wiederstand in der Datenleitung ging es nicht.
Gibt es denn noch ne alternative als die Boardversion zu ändern?
Ist bestimmt schwierig.?

Danke

tom-ruhr, 2021-11-25:
Hey Heiko, das ist einfach. Wenn Du mit der Arduini IDE den Code auf den ESP8266 Chip schiebst dann hilft Dir vielleicht das:
https://blog.opendatalab.de/codeforbuga/2016/07/02/arduino-ide-mit-nodemcu-esp8266
Gruß Tom

pL4uN3r, 2021-11-25:
@heikokehr des is ganz einfach. Im menü "werkzeug" unter "board: 'bla bla bla bla bla' " auf "boardverwalter..." drücken, da in der suchleiste "esp" eingeben, dann kommt irgendwann "esp8266" und wenn du jetzt her mit der maus drüber gehst kommt unten links des drop-down menü zur versions auswahl... hier einfach 2.7.4 auswählen

heikokehr, 2021-11-30:
guten Tag,

kann noch gar nicht fassen, dass mir jemand geantwortet hat, vielen Dank!!!!
hab das ausprobiert und hat auf Anhieb funktioniert!!!! läuft jetzt mit 2.7.4

Vielen Dank nochmal an alle, weiter so!

MichiS79, 2021-12-13:
Guten Abend,
ich habe wie meine Vorredner das selbe Problem doch bei mir startet der ESP bei 2.7.4 nicht mehr sauber. Ich kann die Http Seite weiterhin erreichen doch die Uhr läuft nicht. Mit 3.0.2 tut alles wie gewünscht bis auf der Farbwechsel der 1. LED.
Konnte jemand etwas ähnliches feststellen?
Gibt es irgendwelche Abhängigkeiten zu anderen Bibliotheken oder ist das vom eingesetzten Board zusätzlich abhängig? Ich habe ein NodeMCU V3.3
Vielen Dank vorab.

VG Michael

worldthumbler, 2022-01-17:
Hi Michael,
welche Version von git hast du genommen den master oder 4.0.1? Bei mir läuft es mit V4.0.1 (word clock) auf der Boardversion 3.0.2
Mit dem github master und der Boardversion 3.0.2 lief meine Uhr auch nicht

MichiS79, 2022-01-18:
Hi, Danke für die Rückmeldung. Ich hab den Master genommen und nicht den Release V4.0.1. Werde das die nächsten Tage mal testen ob das was ändert.

oe9mdv, 2022-10-08:
Probier mal mit
häng mal überall nach FastLED.show(); yield(); und FastLED.delay(4); an.
Durch Interrupts glitch't das Signal ein wenig.

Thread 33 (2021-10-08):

Minuten Eck-LEDs, Laufrichtung

lars587, 2021-10-08:
Eck LEDs werden als separate Minuten nicht dargestellt (funktionieren aber bei Hintergrundbeleuchtung)
Kann man aufgrund falscher Anordnung die Reihen (Start oben links) spiegeln.
Klappt trotz Umschreibung der Wortdefinitionen nicht.
Wo liegt mein Fehler?

pL4uN3r, 2021-11-25:
schwer zu sagen ohne den code von dir...
hatte es beim kollege so gemacht, wenn du 10x11 (also 110leds ...0-109) einfach 4 weiter leds dran löten in die ecken und auf 11x11 (also 121... 0-120) in der config einstellen und in der sprachdatei die "led nummern" ändern

`
 if(GRID_SINGLE_MINUTES == 1) {
	// single minutes
        if(singleMinute >= 1) {
	  Led::ids[110].setRGB(Config::color_fg.r, Config::color_fg.g, Config::color_fg.b);   // <--- hier
        }
        if(singleMinute >= 2) {
	  Led::ids[111].setRGB(Config::color_fg.r, Config::color_fg.g, Config::color_fg.b);   // <--- hier
        }
        if(singleMinute >= 3) {
	  Led::ids[112].setRGB(Config::color_fg.r, Config::color_fg.g, Config::color_fg.b);   // <--- hier
        }
        if(singleMinute >= 4) {
	  Led::ids[113].setRGB(Config::color_fg.r, Config::color_fg.g, Config::color_fg.b);   // <--- und hier
        }
  } else {
	for(int s = 0; s < singleMinute; s++) {
	  Led::ids[s].setRGB(Config::color_fg.r, Config::color_fg.g, Config::color_fg.b);
	}
  }
`

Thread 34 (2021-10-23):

LEDs leuchten nach

SkylightXD, 2021-10-23:
Hallo zusammen,

bei mir leuchten ein paar LEDs nach...
Nachts schalte ich die über den Zeitplan aus, aber aktuell leuchten zwei LEDs schwach blau weiter...
Habt ihr eine Idee woran das liegen könnte?
schlechte Verkabelung?
LEDs defekt?

Danke und Grüße

SkylightXD, 2021-11-14:
Ich habe jetzt die Verkabelung verbessert und die hoffentlich letzte defekte LED getauscht ... mal schauen, wie lang das hält ...

Closed 2021-11-14.

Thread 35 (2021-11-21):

geänderter Eingangssatz funktioniert nicht "ES IST"

mawi1986, 2021-11-21:
Hallo Zusammen

Besten Dank erstmals dem Ersteller für den Code!

Ich habe ein kleines Problem mit der Uhr. Ich habe, da ich aus der Schweiz kommen, mir ein neues Layout in Berndeutsch angelegt.
Nun habe ich das Problem, dass der Eingangssatz, obwohl in der Sprachdatei geändert, nicht richtig angesteuert werden!

Folgendes habe ich in den Dateien dazu geändert:
de_DE.h: static int time_it_is[9];
de_DE.cpp: int Grid_de_DE::time_it_is[9] = {  0,  1,  3,  4,  5,  6,  8,  9, 10}; // ES ISCH ÄUÄ

Ob wohl ich die oben geschriebenen Änderungen vorgenommen habe, werden als Eingangssatz nur die LED's 0,1,4,5,6 angesteuert, wie in der Originalen Sprache für "ES IST".

Ist der Eingassatz noch irgendwo anders in einer Datei definiert, oder wie bekommen ich meinen eigenen Eingangssatz zum laufen?

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

pL4uN3r, 2021-11-25:
servus,
in der "user_config.h" auch die richtig sprachdatei ausgewählt "#define GRID_LANGUAGE de_DE" ?
sonst fällt mir spontan nix anderes ein.

mawi1986, 2021-12-19:
Sollte ich gemacht haben...
Habe jedoch in der zwischenzeit auf eine andere Firmware gewechselt...

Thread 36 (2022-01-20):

Erste LED Rot

dreher85, 2022-01-20:
Hallo zusammen,

vorne Weg. Das ist ein wirklich schönes Projekt. Viellen Dank dafür.

Leider habe ich nichts passenden gefunden.
Die Uhr funktioniert soweit. Jedoch ist die erste LED Rot.
Muss ich dies noch in den Einstellungen (config) anpassen?

Vorab vielen Dank
Gruß
Flo

SkylightXD, 2022-01-20:
Moin moin,
hast du mal geprüft, ob die Farbe sich ändert? Bei mir gehen immer wieder LEDs kaputt... Wenn ich die dann tausche ist alles wieder gut :)
Grüße

dreher85, 2022-01-20:
Hi,

also die Farbe der LED ist auf den Standard "Weiss".
Die Led flackern etwas, denke vom aktualisieren etc.
Ansonsten ändert sich nichts und die erste LED bleibt Rot

SkylightXD, 2022-01-20:
Also das E? Bzw. die LED sollte sonst auch weiß leuchten? Ich bin immernoch für tauschen ;)

SkylightXD, 2022-01-20:
Bei mir sieht es so aus

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

dreher85, 2022-01-20:
Ja genau das e leuchtet rot.

Werde es morgen mal mit einer neuen led versuchen.
Hab es allerdings heute erst alles gemacht die Komponenten sind neu.
Aber ein Versuch ist es wert.

Von meinem iPhone gesendet

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

dreher85, 2022-01-20:
Sehe auch gerade du hast eine Zeile wenige.
Bei mir steht in der letzten
EVFXRNZSLPI

Von meinem iPhone gesendet

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

oe9mdv, 2022-01-30:
Probier mal mit
häng mal überall nach FastLED.show();     yield(); und  FastLED.delay(4); an.
Durch Interrupts glitch't das Signal ein wenig.

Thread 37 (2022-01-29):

Time not updating automatically

JanMrt-d, 2022-01-29:
Hey guys,

currently setting up the clock.
First of all, nicework and thank you!

However, as a newbie in C++ I am currently struggeling a little.
My issue:
The ESP8266 does not automatically update the time. If i restart, the correct time is taken from the NTP Server.
Anbyody had this problem?

Tried 4.0.1 and master branch.
Thanks :)

lordwimsey, 2022-04-02:
I have the same problem. Came looking into these issues and found this one. Does anyone have insight into this?

laserbrain-3D, 2022-04-06:
Same to me. Initially the time is correct, but no update on it. Can anyone help?

lordwimsey, 2022-04-09:
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

Thank you for coming back with this!
I ultimately switched to another firmware that is quite bloated with features, so I might consider going back.
Thanks!

JanMrt-d, 2022-04-09:
Thank you, will try it soon :)
________________________________
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

actionski, 2022-09-15:
the simple solution is to put the line
Grid::setTime(Time::hour, Time:::minute);
into the loop - took me ages to realize that this is the reason why everything works fine at start or restart, but no automatic updating

Hill2, 2022-11-10:
I have the same problem with 4.01 version. Does anyone have insight into this? tried the given solutions in this thread but with no result.

Are there other solutions for this problem? I can't get it running now

LaSuze7, 2023-12-13:
Hi,

I have the same problem here. The time is not updating.
I tried using the downgraded versions of FastLED and NTPClient. But this got me some error messages and the script was not compiled. With the latest versions (FastLED V3.6.0, NTPCLient V4.3.1.) I get at least the actual time after a restart.
So I am stuck now.

Does anybody has better skills in C++ coding?

Thanks!

FlorianLang06, 2024-02-14:
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

NTPClient 3.1.0 didn't work for me.

So its working with NTPClient 3.2.0 and FastLED 3.4.0 for me.

This could be a solution for you @LaSuze7

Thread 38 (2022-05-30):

Fehler beim Kompiliren

tho-fi, 2022-05-30:
Ich bekomme immer Folgene Fehlermeldung und einen Abruch beim Kompilieren:

C:\Program Files\Arduino\libraries\WiFiManager/WiFiManager.h:25:24: error: 'const char HTTP_HEAD []' redeclared as different kind of entity
   25 | const char HTTP_HEAD[] PROGMEM            = "<!DOCTYPE html><html lang=\"en\"><head><meta name=\"viewport\" content=\"width=device-width, initial-scale=1, user-scalable=no\"/><title>{v}</title>";
      |                        ^~~~~~~

Ich kann damit nichts anfangen, Libary ist aktuel aber die fehlermeldung bleibt und ich bekomme es nicht Hochgeladen.

Hat da jemand eine idee ??

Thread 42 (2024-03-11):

Frage zum Code

RalphGit62, 2024-03-11:
Hallo,
kann mir jemand die Stelle im Code nennen, an der der Nachtmodus der Uhr scharfgeschaltet wird? Zum eingestellten Zeitpunkt  wird ja die Helligkeit komplett abgedreht. Meine Idee war, ob man an dieser Stellen nicht einfach auf 5% stellen könnte.

Aber wenn ich die Code-Stelle noch nicht mal finde ...)-:
Danke

napsio, 2024-03-11:
Hallo,

in der Grid Datei, z.B. https://github.com/panbachi/wordclock/blob/master/wordclock/src/language/de_DE.cpp in der Zeile 16 wird die Farbe für den Nachtmodus eingestellt.

Hoffe das hilft weiter.

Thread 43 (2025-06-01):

Hat noch jemand das Binary?

Snobs76, 2025-06-01:
Mein Wemos ist kaputt gegangen und ich vercuhe einen neuen zu kompilieren und zu flashen. Nach Stunden habe ich es jetzt soweit, das die Uhrzeit wieder angezeigt wird, aber die Minuten bzw die Uhr läuft nicht weiter. Mein Data PIN ist D3 und die Minuten LEDS sind am Ende. Kamm mir ggf jemand mit einem funktionierendes Binary weiterhelfe, oder mir die Board und Libary Versionen sagen die ich nutzten sollte.
Der neune Mikrokontroller ist auch wieder ein Wemos D1 Mini

Danke & Gruß
Sascha

cz-lucas, 2025-07-27:
Hi,

das Binary habe ich gerade nicht da, aber ich konnte den Code mit den folgenden Versionen kompilieren:
- ArduinoJSON 7.4.1
- Fastled 3.9.16
- NTPClient 3.2.1
- Wifimanager 2.0.17
- ArduinoIDE: 2.1.0
-  ESP8266Core 3.1.2

Viele Grüße

Zippochonda, 2025-08-11:
Ich habe das Binary auch nicht mehr, deshalb habe ich ein Usermod für WLED angepasst. Der PullRequest läuft gerade, ich kann dir  aber die .bin mit aktivierten Usermod schicken.

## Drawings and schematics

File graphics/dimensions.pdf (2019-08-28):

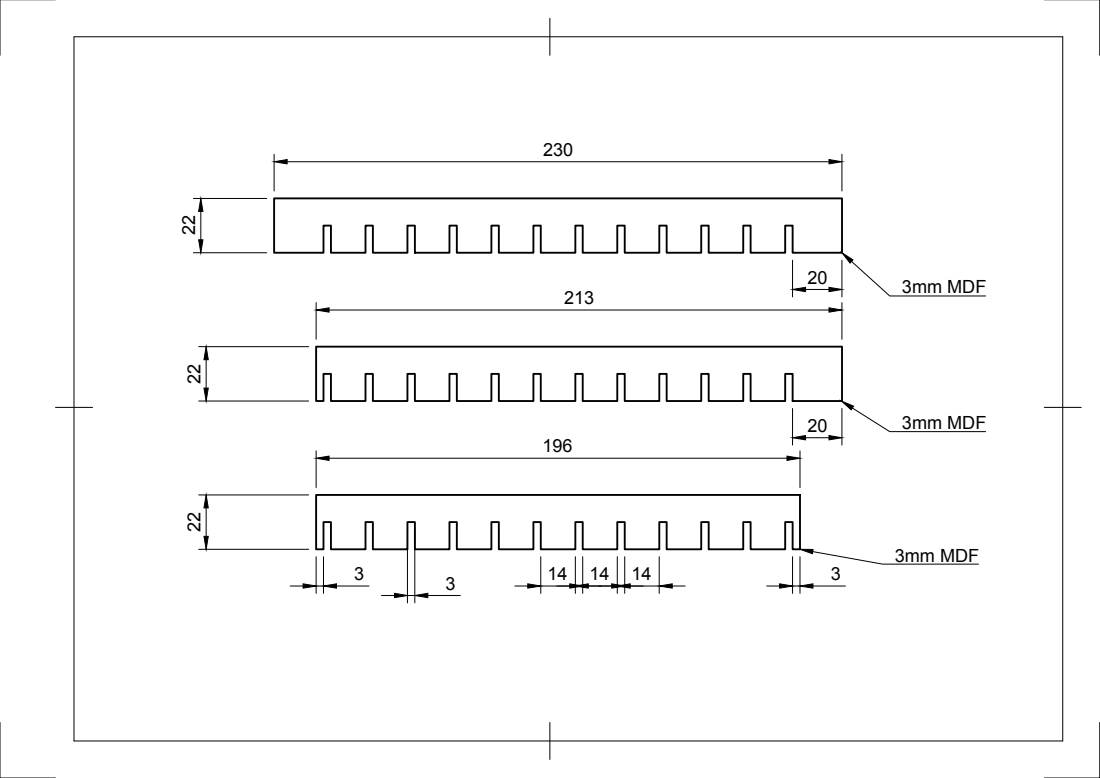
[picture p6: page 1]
3mm MDF

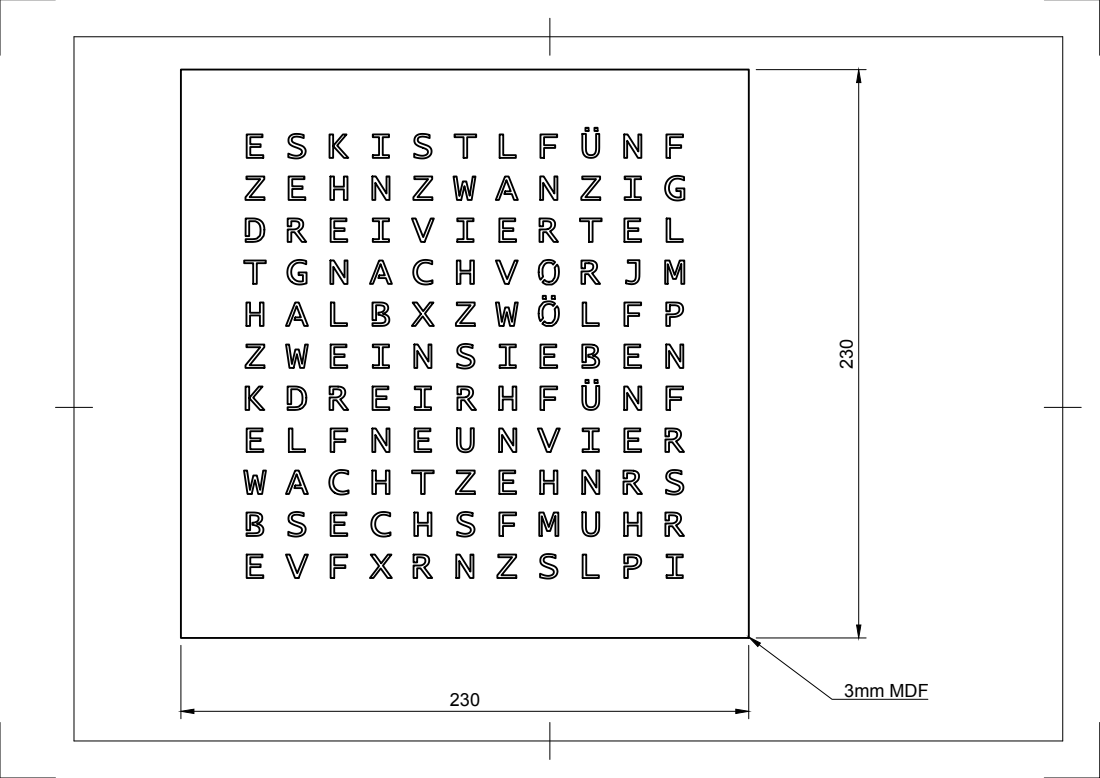
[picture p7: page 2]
3mm MDF

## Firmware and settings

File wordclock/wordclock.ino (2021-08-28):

#include <ArduinoJson.h>
#include <ESP8266WiFi.h>
#include <DNSServer.h>
#include <ESP8266WebServer.h>
#include <WiFiManager.h>
#include <FastLED.h>
#include <NTPClient.h>
#include <WiFiUdp.h>
#include <FS.h>

#include "src/grid.h"
#include "src/wifi.h"
#include "src/types.h"
#include "src/color.h"
#include "src/config.h"
#include "src/dnd.h"
#include "src/led.h"
#include "src/time.h"
#include "src/httpServer.h"
#include "src/gui.h"
#include "src/controller.h"
#include "src/healthcheck.h"

void setup() {
  Serial.begin(115200);
  Serial.println();
  SPIFFS.begin();

  if (DATA_PIN != D4){
    // If we use a data pin different than d4, we will deactivate d4 because it triggers the blue board status led
    // I use D3 as data pin, because d4 is connected with the board led. 
    pinMode(D4, OUTPUT); // Define LED pin as output
    digitalWrite(D4, HIGH); // Switch the blue board status LED OFF
  }

  Config::load();

  Wifi::setup();
  HttpServer::setup();
  Led::setup();
  Time::setup();

  Grid::setTime(Time::hour, Time::minute);
  
  if (Config::healthcheck ){
    // run simple LED check at start (uncomment to deactivate)
    Healthcheck::run();
  }
}

void loop() {
  Time::loop();
  HttpServer::loop();
}

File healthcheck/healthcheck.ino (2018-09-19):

#include <FastLED.h>
#define NUM_LEDS 121
#define DATA_PIN D4

CRGB leds[NUM_LEDS];
    
void setup() {
  FastLED.addLeds<NEOPIXEL, DATA_PIN>(leds, NUM_LEDS);
  FastLED.setBrightness( 40 );

}

void loop() {
  for(int i = 0; i < NUM_LEDS; i++) {
      int led = i;
      leds[led] = CRGB::Red; 
      FastLED.show();
      delay(100);
      
      leds[led] = CRGB::Black;
      FastLED.show();
      delay(100);
    }

    for(int i = 0; i < NUM_LEDS; i++) {
      int led = i;
      leds[led] = CRGB::White; 
      
    }
    FastLED.show();
    delay(5000);

    for(int i = 0; i < NUM_LEDS; i++) {
      int led = i;
      leds[led] = CRGB::Black; 
      
    }

    FastLED.show();
}

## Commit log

2018-09-20 added assemble video
2019-08-28 added dxf files
    [de.dxf, grid_element_large.dxf, grid_element_medium.dxf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]
2019-09-11 optimized plate files
    [de.dxf]
2020-01-15 fixed hour switch
2020-12-08 fix: auto timezone: handle if timezone server is not reachable
    In case the timezone server is not reachable we use know the
    last known timezone instead of falling back to timezone +/-0.
    When the we receive a answer from timezone server, it will be
    checked if the timezone has changed. Only iff the timezone has
    changed the new value will be stored in the config.
    [config.cpp, utcOffset.cpp]
2020-12-10 fix: auto timezone: Only use timezone response with 200 OK
    Only evaluate responses from the timezone provider if the
    answer has the response code 200 OK. Otherwise discard the
    response.
    [utcOffset.cpp]
2020-12-22 change grid to front Plate
2021-08-19 added led healthcheck settings
2021-08-19 fixed healthcheck config typo
    [config.cpp]
2021-08-19 add new rounded clock
    it rounds the time to the next 5 minutes and shows the difference on the extra leds (5 leds needed)
2021-08-19 ESP8266 fix for new version
    [utcOffset.cpp]
2021-08-19 deactivate wemos status LED if not used for the led stripe
